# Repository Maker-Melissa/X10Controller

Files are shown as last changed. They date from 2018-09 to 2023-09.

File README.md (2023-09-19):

# X-10 Controller
X-10 Controller Interface for the FireCracker CM17a Module

## Description
This is designed to run on an ESP8266. I currently have it running on an AdaFruit Feather Huzzah with a 0.96" OLED Display. It starts by connecting to WiFi and then to the specified MQTT Server and awaits commands. You can test it out by running MQTT.Fx for the Mac or Windows or whatever your favorite client is. After launching, click the ear and make sure the IP Address of your MQTT server is in the Broker Address field and the Broker Port is 1883. Then connect to the server, use the SubScribe Topic you specified in the firmware file and post a message.

## Required Libraries
In order to compile successfully, there are a few additional required libraries to be added with the Arduino Library Manager.
* U8g2
* MQTT by Joel Gaehwiler
* ESP8266mDNS
* ESP8266WebServer
* ESP8266WiFi
* ESP8266HTTPUpdateServer

## Wiring

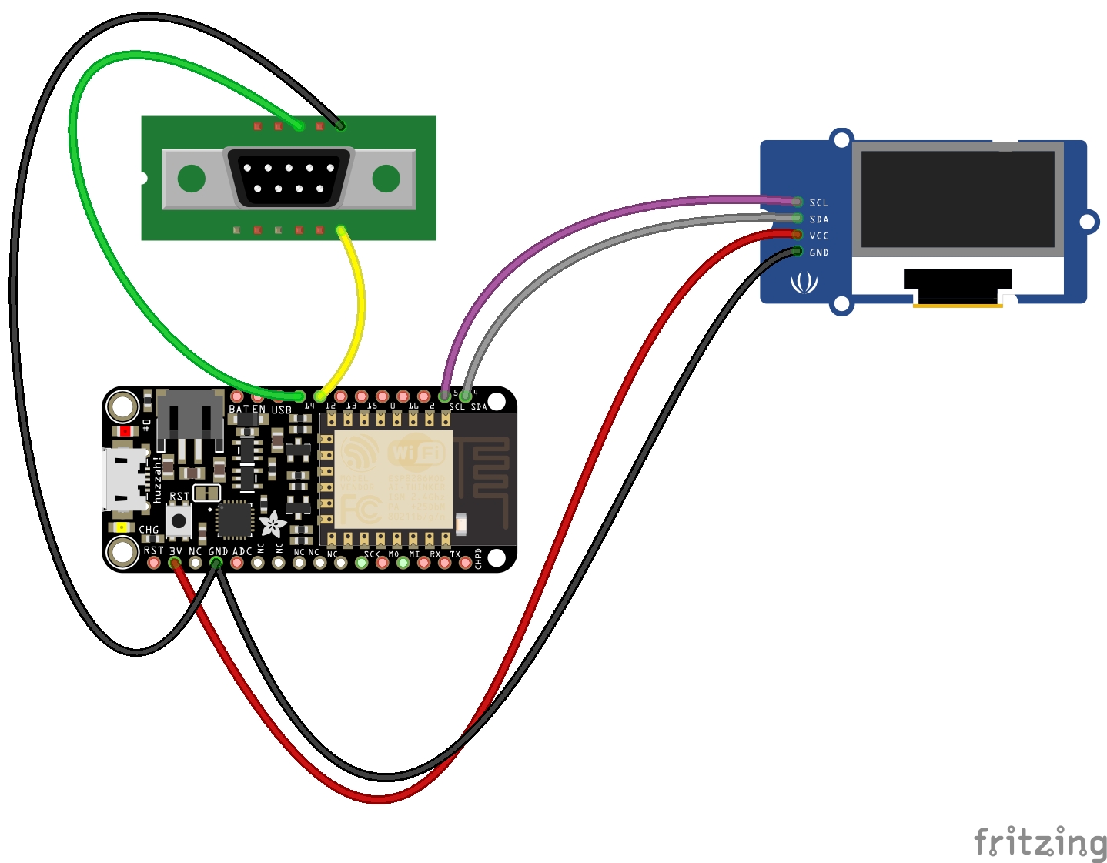
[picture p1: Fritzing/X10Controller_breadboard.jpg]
X10Controller_breadboard


## Schematic

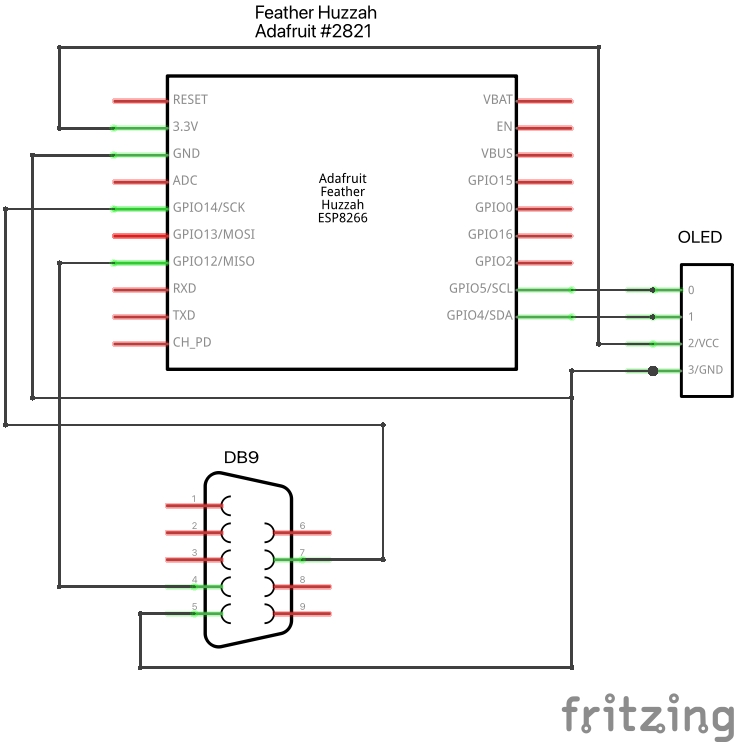
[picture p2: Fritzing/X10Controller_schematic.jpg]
X10Controller_schematic


## MQTT Message Format

For the message, it should be in the following format in all capital letters:

`COMMAND-HOUSE-DEVICE`

COMMAND should be one of: ON, OFF, DIM, BRIGHT
HOUSE should be a single capital letter of A through P specifying the House Code of the device
DEVICE Should either be a number between 1 and 16, ALL to address all devices, or LAMPS to address Lamps only

Each data piece should be separated by a single hyphen.

So the Following examples should work:

`ON-D-12` to Turn On Device 12 in House D
`OFF-B-LAMPS` to Turn Off All Lamps in House B
`ON-A-ALL` to Turn On All Lamps and Appliances in House A

## OpenHab Setup
### Items
To set up an X10 Module in the items file, here is an example to get it to function in an on off capacity
```
Switch X10ApplianceModule1 "Appliance" <switch> {mqtt=">[broker:MySmartHome/utilities/X10Controller:command:ON:ON-A-1],>[broker:MySmartHome/utilities/X10Controller:command:OFF:OFF-A-1]"}
Dimmer X10LampModule1 "Lamp" <light> {mqtt=">[broker:MySmartHome/utilities/X10Controller:command:ON:ON-A-2],>[broker:MySmartHome/utilities/X10Controller:command:OFF:OFF-A-2]"}
```

### Sitemap
```
sitemap home label="My Home"
{
        Frame label="Room 1"
        {
                Switch item=X10ApplianceModule1
        }

        Frame label="Room 2"
        {
                Switch item=X10LampModule1
        }
}
```

### Rules
I found I didn't need to set any rules to use this, but I also haven't got the dimmer working yet

## Limitations
Although the FireCracker can transmit any house code, the codes are limited to the House Code of the Receiving Module. To use more than one house, you will need multiple receivers.

Even though the Dim and Bright commands require a Device ID, they will only function on the last device that had an On/Off command sent and in 20% increments from their current setting.

I don't believe there is currently a way to poll the status of devices with the FireCracker, but using OpenHab does a nice job of keeping track of the state of the devices unless you change them either through another X10 Device or turn the device on through turning the connected device off and on.

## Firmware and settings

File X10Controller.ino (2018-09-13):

/*
 * X-10 Controller Interface
 * 
 * Author: Melissa LeBlanc-Williams
 * Website: https://melissagirl.com
 * 
 * Additional Libraries Required to Compile
 * U8g2
 * MQTT by Joel Gaehwiler
 * ESP8266mDNS
 * ESP8266WebServer
 * ESP8266WiFi
 * ESP8266HTTPUpdateServer
 *
 * X10 FireCracker Library created by BroHogan and updated by Melissa LeBlanc-Williams
 * 
 * Note: After flashing the code once you can remotely access your device by going to http://HOSTNAMEOFDEVICE.local/firmware 
 * obviously replace HOSTNAMEOFDEVICE with whatever you defined below. The user name and password are also defined below.
 *
 */

// X10 FireCracker
#include "X10FireCracker.h"

// OLED
#include <Wire.h>
#include <U8g2lib.h>

// WiFi
#include <ESP8266WiFi.h>

// Update server
#include <ESP8266WebServer.h>
#include <ESP8266mDNS.h>
#include <ESP8266HTTPUpdateServer.h>

// MQTT
#include <MQTTClient.h>

#define BIT_DELAY 1

// Initialize the OLED Display
U8G2_SSD1306_128X64_NONAME_F_SW_I2C u8g2(U8G2_R0, /* clock=*/ SCL, /* data=*/ SDA, /* reset=*/ U8X8_PIN_NONE);

/* DO NOT CHANGE ANY SETTINGS ABOVE THIS LINE */

/* Serial Pin Settings */
#define RTS_PIN 14  // DB9 Pin 7
#define DTR_PIN 12  // DB9 Pin 4

/* WIFI Settings */
const char* ssid = "WiFi SSID";
const char* password = "WiFi Password";

/* Web Updater Settings */
// Host Name of Device
const char* host = "X10Controller";

// Path to access firmware update page (Not Neccessary to change)
const char* update_path = "/firmware";

// Username to access the web update page
const char* update_username = "admin";

// Password to access the web update page
const char* update_password = "password";

/* MQTT Settings */
const char* mqttServer = "192.168.11.6";
const char* subscribeTopic = "MySmartHome/utilities/X10Controller";
const char* mqttDeviceID = "X10Controller1"; 

/* Time in seconds until screen is cleared. Set to 0 to disable. */
int screenClearTimeout = 5;

/* DO NOT CHANGE ANY SETTINGS BELOW THIS LINE */

unsigned long millisSinceLastEvent = 0;

// Web Server 
ESP8266WebServer httpServer(80);
ESP8266HTTPUpdateServer httpUpdater;

WiFiClient espClient;
MQTTClient client;

void setup() 
{
  X10.init(RTS_PIN, DTR_PIN, BIT_DELAY);
  u8g2.begin();
  connectWifi();
  client.begin(mqttServer, espClient);
  client.onMessage(messageReceived);

  MDNS.begin(host);

  httpUpdater.setup(&httpServer, update_path, update_username, update_password);
  httpServer.begin();

  MDNS.addService("http", "tcp", 80);  
}

void loop()
{
  if (!client.connected()) {
    connectMQTT();
  }
  
  client.loop();
  delay(10);
  
  httpServer.handleClient();

  if (screenClearTimeout > 0 && millis() - millisSinceLastEvent > screenClearTimeout * 1000) {
    // Clear the screen
    startOled();
    outputOled();
  }
}

void connectWifi() {
  delay(10);

  startOled();
  u8g2.setCursor(0, 35);
  u8g2.print("Connecting to ");
  u8g2.print(ssid);
  outputOled();

  // Start WiFi
  WiFi.mode(WIFI_STA);
  WiFi.begin(ssid, password);

  // Animated Connection Message while Connecting
  while (WiFi.status() != WL_CONNECTED) {
    delay(125);
    printMessage("Connecting");
    delay(125);
    printMessage("Connecting.");
    delay(125);
    printMessage("Connecting..");
    delay(125);
    printMessage("Connecting...");
  }

  // WiFi Info
  startOled();
  u8g2.setCursor(0, 20);
  u8g2.print("WiFi connected");
  u8g2.setCursor(0, 35);
  u8g2.print("IP address:");
  u8g2.setCursor(0, 50);
  u8g2.print(WiFi.localIP());
  outputOled();
}

void connectMQTT() {
  startOled();
  u8g2.setCursor(0, 10);
  u8g2.print("Attempting MQTT");
  u8g2.setCursor(0, 25);
  u8g2.print("connection...");
  u8g2.setCursor(0, 40);

  // Loop until we're reconnected
  while (!client.connect(mqttDeviceID)) {
    delay(1000);
  }

  u8g2.print("Connected!");
  u8g2.setCursor(0, 55);
  u8g2.print("Listening...");
  outputOled();
  
  // ... and subscribe
  client.subscribe(subscribeTopic);
  millisSinceLastEvent = millis();
}

void messageReceived(String &topic, String &payload) {
  byte error = 0;
  String tokens[3];
  int token = 0;
  int tokenStart = 0;
  int tokenEnd = 0;
  
  HouseCode houseCode;
  int deviceId = 0;
  CommandCode command;

  // Separate the message into tokens
  for (int i = 0; i < payload.length(); i++) {
    if (payload.charAt(i) == '-') {
      tokens[token] = payload.substring(tokenStart, i);
      tokenStart = i + 1;
      token++;

      if (token > sizeof(tokens)) {
        break;
      }
    }
  }

  // Grab the final token
  tokens[token] = payload.substring(tokenStart, payload.length()); 
  
  if (tokens[0] == "ON") {
    command = cmdOn;
  } else if (tokens[0] == "OFF") {
    command = cmdOff;
  } else if (tokens[0] == "BRIGHT") {
    command = cmdBright;
  } else if (tokens[0] == "DIM") {
    command = cmdDim;
  } else {
    error = 1;
  }

  char houseLetter = tokens[1].c_str()[0];
  if (houseLetter >= 'A' && houseLetter <= 'P') {
    houseCode = (HouseCode)(houseLetter - 'A');
  } else {
    error = 1;
  }
  
  if (tokens[2].toInt() >= 1 && tokens[2].toInt() <= 16) {
    deviceId = tokens[2].toInt();
  } else if (tokens[2] == "ALL" && command == cmdOn) {
    command = cmdAllOn;
  } else if (tokens[2] == "ALL" && command == cmdOff) {
    command = cmdAllOff;
  } else if (tokens[2] == "LAMPS" && command == cmdOn) {
    command = cmdLampsOn;
  } else if (tokens[2] == "LAMPS" && command == cmdOff) {
    command = cmdLampsOff;
  } else {
    error = 1;
  }

  if (error == 0) {
    sendCommand(houseCode, deviceId, command);
  } else {
    printMessage("Error: Bad Format");
  }
  millisSinceLastEvent = millis();
}

void startOled() {
  u8g2.clearBuffer();          // clear the internal memory
  u8g2.setFont(u8g2_font_ncenB08_tr); // choose a suitable font  
}

void outputOled()
{
  u8g2.sendBuffer();          // transfer internal memory to the display
}

void printMessage(const char *s)
{
  startOled();
  u8g2.setCursor(0, 35);
  u8g2.print(s);  // write something to the internal memory
  outputOled();
}

// Send a command and Display command Info on OLED
void sendCommand(HouseCode houseCode, int deviceId, CommandCode command) {
  u8g2.clearBuffer();          // clear the internal memory
  u8g2.setFont(u8g2_font_ncenB08_tr); // choose a suitable font
  u8g2.setCursor(30, 10);
  
  u8g2.print("Sending ");
  u8g2.setCursor(30, 25);
  if (command == cmdOn) {
    u8g2.print("ON");
  } else if (command == cmdOff) {
    u8g2.print("OFF");
  } else if (command == cmdBright) {
    u8g2.print("BRIGHT");
  } else if (command == cmdDim) {
    u8g2.print("DIM");
  } else if (command == cmdAllOn) {
    u8g2.print("ALL ON");
  } else if (command == cmdAllOff) {
    u8g2.print("ALL OFF");
  } else if (command == cmdLampsOn) {
    u8g2.print("LAMPS ON");
  } else if (command == cmdLampsOff) {
    u8g2.print("LAMPS OFF");
  } else {
    u8g2.print("UNKNOWN");
  }
  
  u8g2.setCursor(30, 40);
  u8g2.print("House: ");
  char houseLetter = 'A' + houseCode;
  u8g2.print(houseLetter);

  if (deviceId > 0) {
    u8g2.setCursor(30, 55);
    u8g2.print("Device: ");
    u8g2.print(deviceId);
  }

  u8g2.sendBuffer();          // transfer internal memory to the display

  X10.sendCmd(houseCode, deviceId, command);
}

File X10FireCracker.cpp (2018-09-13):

/* 
 * Arduino Interface to the CM17A Wireless X10 dongle. BroHogan 7/19/08
 * Arduino Library Conversion by DaveK AC0KG
 * Updated to Compile With Arduino 1.8.5 by Melissa LeBlanc-Williams
 * Additional Commands added by Melissa LeBlanc-Williams
 *
 * The CM17A gets it power and data using only the RTS, CTS, & Gnd lines.
 * A MAX232 is not req. (0/+5V work OK) If MAX232 IS used reverse all HIGHs & LOWS
 * Signal      RTS DTR        Standby | '1' | Wait | '0' | Wait | '1' | Wait...
 * Reset        0   0         _____________________       _____________________
 * Logical '1'  1   0   RTS _|                     |_____|
 * Logical '0'  0   1         ________       ___________________       ________
 * Standby      1   1   DTR _|        |_____|                   |_____|
 *
 * MINIMUM time for the '1', '0' and 'Wait' states is 0.5ms.
 *
 * At least one signal must be high to keep CM17A powered while transmitting.
 *
 * Each xmit is 40 bits -> "Header" 16 bits,  "Data" 16 bits, "Footer" 8 bits
 *
 * CONNECTION: RTS -> DB9 pin 7  
 *             DTR -> DB9 pin 4 
 *             Gnd -> DB9 pin 5
 */

#include <Arduino.h>

#include "X10FireCracker.h"

// An instance of the EventFuse class
X10FireCracker X10 = X10FireCracker();

// This will generate a warning "only initialized variables can 
// be placed into program memory area". Apparently this is a compiler
// bug, can't do much about it.
uint16_t houseCode[] PROGMEM = {
  0x6000,  // A
  0x7000,  // B
  0x4000,  // C
  0x5000,  // D
  0x8000,  // E
  0x9000,  // F
  0xA000,  // G
  0xB000,  // H
  0xE000,  // I
  0xF000,  // J
  0xC000,  // K
  0xD000,  // L
  0x0000,  // M
  0x1000,  // N
  0x2000,  // O
  0x3000,  // P
};

// This will generate a warning "only initialized variables can 
// be placed into program memory area". Apparently this is a compiler
// bug, can't do much about it.
uint16_t deviceCode[] PROGMEM = {
  0x0000,  // 1
  0x0010,  // 2
  0x0008,  // 3
  0x0018,  // 4
  0x0040,  // 5
  0x0050,  // 6
  0x0048,  // 7
  0x0058,  // 8
  0x0400,  // 9
  0x0410,  // 10
  0x0408,  // 11
  0x0418,  // 12
  0x0440,  // 13
  0x0450,  // 14
  0x0448,  // 15
  0x0458,  // 16
};

// This will generate a warning "only initialized variables can 
// be placed into program memory area". Apparently this is a compiler
// bug, can't do much about it.
uint16_t cmndCode[] PROGMEM = {
  0x0000,  // cmdOn
  0x0020,  // cmdOff
  0x0088,  // 20% cmdBright (0x00A8=5%)
  0x0098,  // 20% cmdDim    (0x00B8=5%)
  0x0080,  // cmdAllOff
  0x0091,  // cmdAllOn
  0x0084,  // cmdLampsOff
  0x0094,  // cmdLampsOn
};


X10FireCracker::X10FireCracker()
{
}

void X10FireCracker::init( int _RTS_Pin, int _DTR_Pin, int _Bit_Delay )
{
  RTS_pin = _RTS_Pin;
  DTR_pin = _DTR_Pin;
  Bit_delay = _Bit_Delay;
  
  pinMode(RTS_pin, OUTPUT);             // RTS -> DB9 pin 7
  pinMode(DTR_pin, OUTPUT);             // DTR -> DB9 pin 4
}

void X10FireCracker::sendCmd(HouseCode house, int device, CommandCode cmnd)
{
  unsigned int dataBuff = 0;
  byte messageBuff[5];

  // Build message by ORing the parts together. No device if Bright or Dim,
  // the bright and dim codes operate on the last-addressed device.
  // Also no device for addressing All
  if ((cmnd == cmdOn) | (cmnd == cmdOff)) {
    dataBuff =  pgm_read_word_near(houseCode  + house     )
              | pgm_read_word_near(deviceCode + (device-1)) 
              | pgm_read_word_near(cmndCode   + cmnd      );
  } else { 
    dataBuff =  pgm_read_word_near(houseCode  + house) 
              | pgm_read_word_near(cmndCode   + cmnd );
  }

  // Build a string for the whole message 
  messageBuff[0] = 0xD5;               // Header byte 0 11010101 = 0xD5 
  messageBuff[1] = 0xAA;               // Header byte 1 10101010 = 0xAA 
  messageBuff[2] = dataBuff >> 8;      // MSB of dataBuff
  messageBuff[3] = dataBuff & 0xFF;    // LSB of dataBuff
  messageBuff[4] = 0xAD;               // Footer byte 10101101 = 0xAD

  // Now send it out to CM17A 
  digitalWrite(DTR_pin, LOW);  // reset device - both low is power off
  digitalWrite(RTS_pin, LOW);
  delay(Bit_delay);

  digitalWrite(DTR_pin, HIGH); // standby mode - supply power
  digitalWrite(RTS_pin, HIGH);
  delay(35);                   // need extra time for it to settle

  for  (byte i = 0; i < 5; i++) {
    for (byte mask = 0x80; mask; mask >>= 1) {
      if (mask & messageBuff[i]) 
        digitalWrite(DTR_pin, LOW);   // 1 = RTS HIGH/DTR-LOW
      else 
        digitalWrite(RTS_pin, LOW);   // 0 = DTR-HIGH/RTS-LOW
      delay(Bit_delay);                 // delay between bits

      digitalWrite(DTR_pin,HIGH);       // wait state between bits
      digitalWrite(RTS_pin,HIGH);
      delay(Bit_delay);
    }  
  }
  delay(1000);                           // wait required before next xmit
}
